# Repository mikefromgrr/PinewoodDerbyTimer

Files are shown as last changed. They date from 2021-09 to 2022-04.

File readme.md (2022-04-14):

# Overview
This is a Pinewood Derby race timer software system designed to run on an ESP32-based microcontroller with support for a 128x32 monochrome SSD1306 OLED screen. Race results are shown on scren and relayed via serial connection (9600,8,N,1). Expects 4 racing lanes. Software tweaks could be made easily to support more (with most of the work to dispaly the results to the OLED screen).

Timing accuracy on the ESP32 hardware below is about two ten-thousandths of a second (0.0002). In other words, it takes .0002 seconds to loop through 4 sensors to determine if they are tripped.

A button press toggles between 3 display modes (race view, lane detection, and raw sensor output).

It's primarily designed to interface with a Windows laptop running the [GrandPrix Race Manager](http://grandprix-software-central.com/index.php/shopping/category/70-grandprix-race-manager) software, though it can likely be used with other derby management software.

### No Support For:
* Racing Light Tree
* Solenoid Gate Releases
* Lane Masking

Though it shouldn't be too difficult to add support for any of these.

## License
You cannot use this software or any derivative of it for commercial purposes (e.g. sell a hardware timer based off of this design/code). 

# Hardware
Designed for ESP32 WeMos Mini D1 ESP-WROOM-32.

## ESP32
* https://www.aliexpress.com/item/1005001621896126.html
* Cost: About $3.81 USD in March 2021, plus shipping.
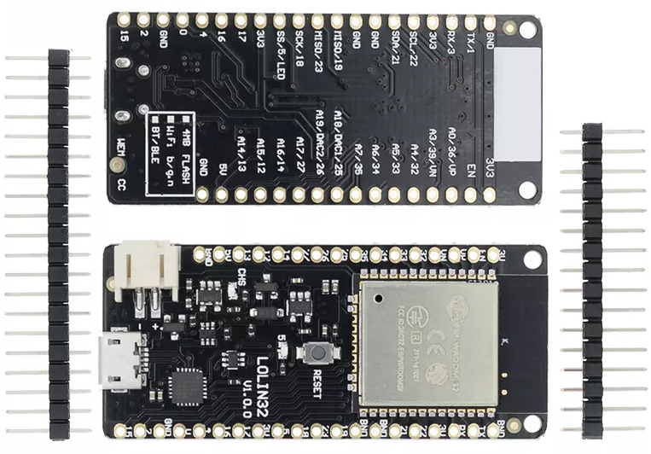
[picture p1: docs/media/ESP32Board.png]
ESP32
* 
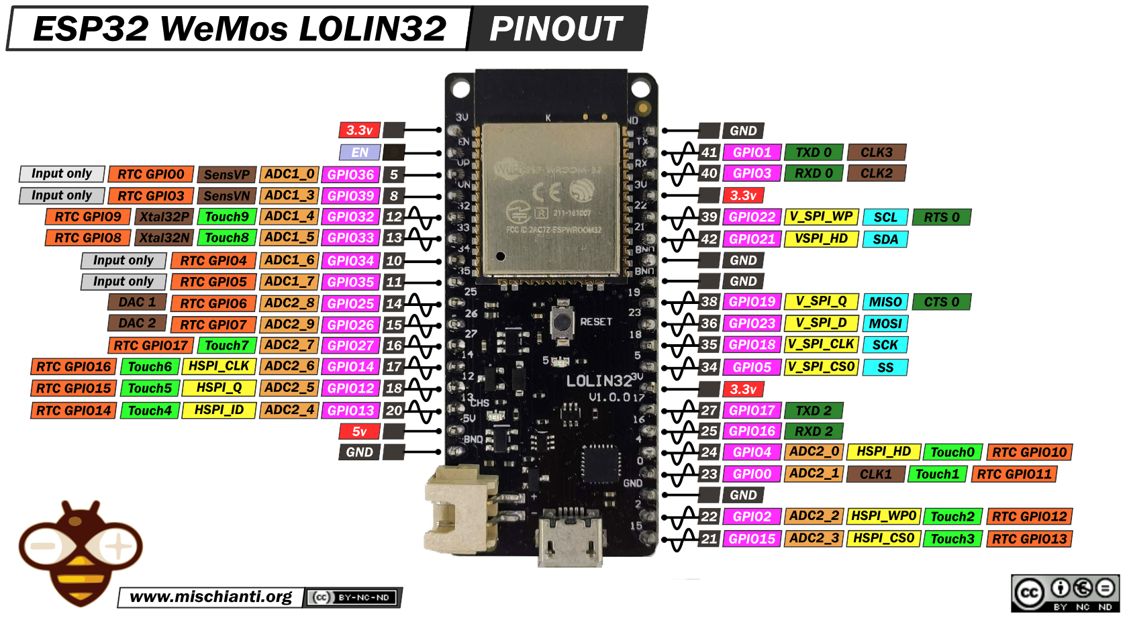
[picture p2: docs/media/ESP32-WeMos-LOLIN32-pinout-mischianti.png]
Pin Out (https://www.mischianti.org/2021/07/30/esp32-wemos-lolin32-lite-high-resolution-pinout-and-specs/ "ESP32 Wemos Lolin32 Pinout")
* 

## SSD1306 Serial OLED Screen
* https://www.aliexpress.com/item/1005001621806398.html
* Cost: About $1.80 USD in July 2021, plus shipping.
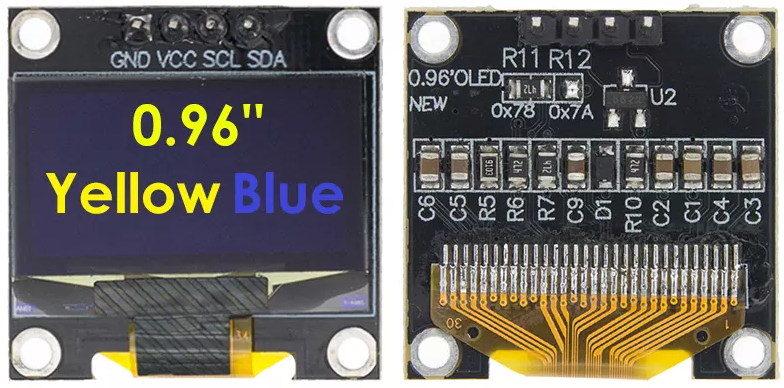
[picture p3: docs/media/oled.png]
SSD1306
* 

## Other
* 2 Small LEDs (for gate status and racing status)
* Light-base lane sensors (tested with a set from an ancient [NewBold DT8000 Timer](https://www.pinewood-derby-timer.com/DT8000.html)); imagine most should work; software reads analog sensor expecting a fully-lit condition to register 4095, and a tripped-condition to be 3500 or less, though this can be tweaked in the code
* Miscellaneous Lane Connectors
* Gate Connector
* [Tactile Push Button Switches](https://www.aliexpress.com/item/32814651113.html)
* [3D Printable Enclosure - Fusion 360 File](docs/3D/ESP32DerbyRaceTimerBox].f3d)

# Compilation
Use [VSCode](https://code.visualstudio.com/Download). Install [PlatformIO extension](https://docs.platformio.org/en/latest/integration/ide/vscode.html). See [platformio.ini](platformio.ini) for configuration details.

# GrandPrix Race Manager Setups
Tested on GPRM15 and GPRM20. See [details here](http://grandprix-software-central.com/index.php/software/faq/search/cat/10-hardware-settings#faq_95).
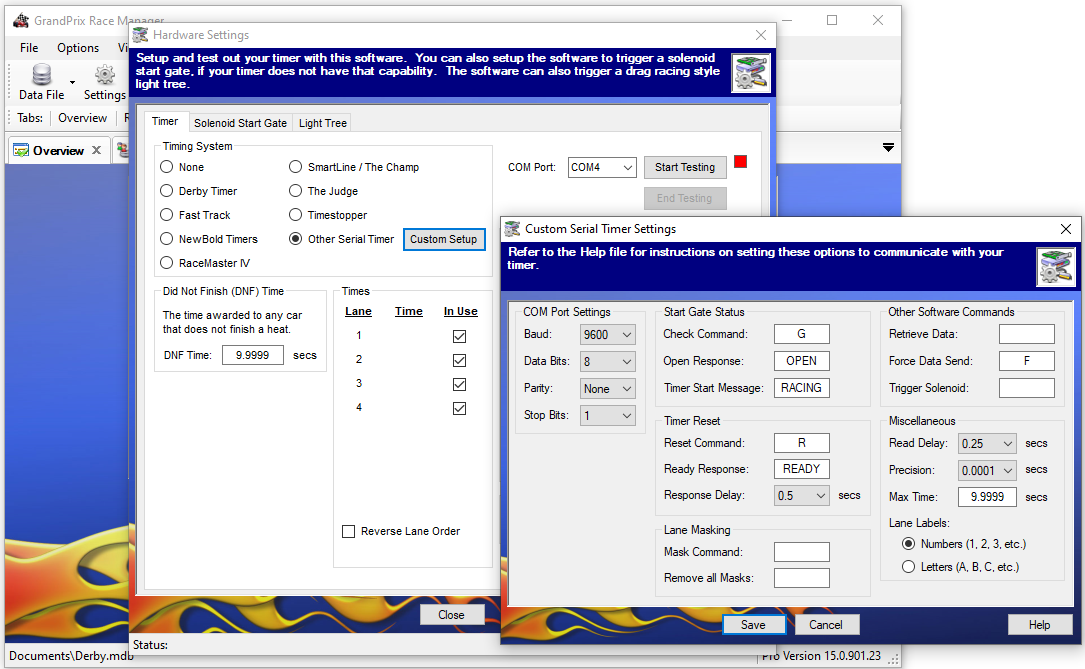
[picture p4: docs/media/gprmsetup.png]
GrandPrix Race Manager Setup


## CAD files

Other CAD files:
docs/3D/ESP32DerbyRaceTimerBox].f3d

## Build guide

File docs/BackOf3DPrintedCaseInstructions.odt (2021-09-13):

Use micro USB connector to connect PC. Designed to work with exactly 4 lanes, no more, no less. Lane pins 1 thru 4 are the farthest from the gate switch. Press mode button to see lane status. When connected and lanes are fully lit, numbers should read a steady 4095. Polarity of lane connectors are important. When cars pass over sensors, shadows are cast and the sensor reads lower. Launch gate needs a complete circuit to read ready (green LED). When racing, purple LED is illuminated.

Driver (if needed)

Silicon Labs CP210x USB to UART Bridge https://www.silabs.com/developers/usb-to-uart-bridge-vcp-drivers

Source Code and More Info

https://github.com/mikefromgrr/PinewoodDerbyTimer

Print and affix to back of 3D Printed case.

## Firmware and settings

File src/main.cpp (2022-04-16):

#include <Arduino.h>
#include <Bounce2.h>
#include <SPI.h>
#include <Wire.h>
#include <TimerScreen.h>

// ESP32 WROOM32 Lolin Pinout: https://www.mischianti.org/wp-content/uploads/2020/11/ESP32-WeMos-LOLIN32-pinout-mischianti.png
// More Details: https://www.mischianti.org/2021/07/30/esp32-wemos-lolin32-lite-high-resolution-pinout-and-specs/
#define TRIGGER_PIN 2                   //connect to GND
#define RACING_LED 17                   //connect negative/cathode lead to GND
#define RACING_LED_CHANNEL 1
#define GATESTATUS_LED 16               //connect negative/cathode lead to GND
#define GATESTATUS_LED_CHANNEL 0        //for PWM Dimming
#define MODESWITCH_PIN 12               //connect to GND
#define EXTRABUTTON_PIN 14              //future use, connect to GND
#define SENSOR_THRESHOLD 3500
#define MAX_RACE_TIME_IN_SECONDS 9.9999
#define BRIGHTNESS_LOW 10
#define BRIGHTNESS_OFF 0

// https://grandprix-software-central.com/index.php/software/faq/faq/95-gprm-custom - Details for GPRM
#define COMMAND_GATE_CHECK 'G'                         //This command will ask the timer to check if the start gate is open or not.
#define COMMAND_TIMER_RESET 'R'                        //This command will tell the timer to reset itself so it is ready for the next heat. Any results or indications of finish order should be cleared from the computer screen and the timer's display.
#define COMMAND_FORCE_DATA_SEND 'F'                    //This command is used if you want to halt the timing (e.g. a car doesn't finish or there is an empty lane). If supported by the timer, pressing the Escape key will prompt the timer to return whatever data that it does have. In this case, any cars that had not finished will be given the maximum time. This command is not necessary if the timer sends the data for a lane as soon as the lane has finished timing. If the timer doesn't support this command, then you must wait until the timer times out before the results will be displayed on screen.
const char *RESPONSE_TIMER_READY = "READY";            //This command will tell the timer to reset itself so it is ready for the next heat. Any results or indications of finish order should be cleared from the computer screen and the timer's display.
const char *RESPONSE_GATE_OPEN = "GATE OPEN";          //This is the response that the timer will send back to indicate that the start gate is open.
const char *RESPONSE_GATE_CLOSED = "GATE CLOSED";      //This is the response that the timer will send back to indicate that the start gate is closed.
const char *RESPONSE_TIMER_STARTED_MESSAGE = "RACING"; //This is the message that the timer will send back to indicate that the heat has started (start gate has opened).
const uint8_t LANE_PINS[8] = {33, 32, 39, 36, 34, 35, 25, 26}; // 1st four are right, unsure about the rest
const short SCREENMODE_LANETIMES = 0;
const short SCREENMODE_SENSOR_OUTPUT = 1;
const short SCREENMODE_LANE_SUMMARY = 2;
const short SCREENMODE_SOFTWARE_IS_RACE_READY = 3;
const unsigned long MAX_LONG = 4294967295;
short LED_PIN = LED_BUILTIN;

using namespace std;

enum LaneStatus
{
  Racing,
  Finished,
  TooSlow,
  NotInUse // lane cannot be found during boot
};
enum TriggerStatus // aka Gate
{
  ReadyToRelease,
  Released
};
enum RaceStatus
{
  Idle,
  RaceInProgress,
  RaceDone
};
struct LaneInfo
{
  unsigned int pin;
  int laneNumber;
  LaneStatus status;
  unsigned long finishTime;
  unsigned long raceDuration;
};


// Global Variables
RaceStatus raceStatus;
TriggerStatus triggerStatus;

unsigned long raceBegin = 0;
unsigned long raceEnd = 0;
short NUM_LANES = 4; // Number of lanes the device is capable to monitor.
short screenMode = 0; 

TimerScreen screen;
Bounce trigger = Bounce();
Bounce screenModeButton = Bounce();
Bounce extraButton = Bounce();
vector<LaneInfo> Lanes; // essentially an array of Lanes

// Computes the time in seconds from beginning of race
float getTimeInSeconds(long durationInMicros)
{
  return (durationInMicros / 1000000.0);
}

// Computes the time in seconds from beginning of race
unsigned long computeDuration(unsigned long raceBeginTime, unsigned long endTime)
{
  unsigned long durationInMicros = 0;
  if (endTime < raceBeginTime)
  {
    // We overflowed the micros() limit (about every 50 minutes of ON time)
    durationInMicros = (MAX_LONG - raceBeginTime) + endTime;
  }
  else
  {
    durationInMicros = endTime - raceBeginTime;
  }
  return durationInMicros;
}

RaceStatus checkForTooLongOfARace()
{
  unsigned long currentMicros = micros();
  long currentDuration = computeDuration(raceBegin, currentMicros);
  if (getTimeInSeconds(currentDuration) > MAX_RACE_TIME_IN_SECONDS)
  {
    // Abort race, too long;
    for (auto& lane : Lanes)
    {
      if (lane.status != Finished)
      {
        lane.raceDuration = (MAX_RACE_TIME_IN_SECONDS * 1000000);
        lane.finishTime = 0;
        lane.status = TooSlow;
      }
    }
    raceEnd = currentMicros;
    return RaceDone;
  }
  return RaceInProgress;
}

RaceStatus pollLanes()
{
  // Poll lanes
  unsigned short int finishCount = 0;
  unsigned long currentMicros = micros();
  for (auto& lane : Lanes)
  {
    if (lane.status == Racing)
    {
      uint16_t sensorValue = analogRead(LANE_PINS[lane.pin]);
      // if (random(1, 10000) > 3) sensorValue = SENSOR_THRESHOLD + 1; //introduce some randomness for testing the sort. hey, wheres the unit tests?
      if (sensorValue < SENSOR_THRESHOLD)
      {
        // Sensor tripped, record time
        lane.finishTime = currentMicros;
        lane.raceDuration = computeDuration(raceBegin, currentMicros);
        lane.status = Finished;
        finishCount++;
      }
    }
    else
    {
      // Lane is already finished
      finishCount++;
    }
  }
  if (finishCount >= NUM_LANES)
  {
    raceEnd = micros();
    return RaceDone;
  }

  return checkForTooLongOfARace();
}

void initializeLanesForRacing(LaneStatus newLaneStatus)
{
  for (auto& lane : Lanes)
  {
    lane.finishTime = 0;
    lane.raceDuration = 0;
    lane.status = newLaneStatus;
  }
}

TriggerStatus getTriggerStatus(int input)
{
  if (input == LOW)
  {
    return ReadyToRelease;
  }
  return Released;
}

void AdjustIndicatorLED(short channel, short brightness) {
  ledcWrite(channel, brightness);
}

void detectPresenceOfLanes() {
    // Clear and reserve space in the Lanes vector/array
    Lanes.clear();
    Lanes.reserve(NUM_LANES);
    
    // Detect and register lanes
    unsigned short int activeLaneCount = 0;
    for (unsigned short int i = 0; i < NUM_LANES; i++)
    {
      uint16_t sensorValue = analogRead(LANE_PINS[i]);
      LaneStatus ls = Finished;
      if (sensorValue < SENSOR_THRESHOLD) {
        ls = NotInUse;
      } else {
        activeLaneCount++;
      }
      Lanes.push_back((struct LaneInfo){.pin=i, .laneNumber=i+1, .status=ls, .finishTime = 0, .raceDuration = 0});
    }
  
    char buffer[200]; 
    String result;
    result.clear(); 
    
    sprintf(buffer,"Detected\n%d Lanes\n", activeLaneCount);
    result.concat(buffer);

    // List Lane Numbers
    for (auto& lane : Lanes)
    {
      sprintf(buffer,"%i", lane.laneNumber);
      result.concat(buffer);
    }

    result.concat('\n');

    // List Lane Status
    for (auto& li : Lanes)
    {
      if (li.status == NotInUse) {
        sprintf(buffer,"X");
      } else {
        sprintf(buffer,"%i", li.laneNumber);
      }

      result.concat(buffer);
    }

    // Output to Screen
    Serial.println(result);
    screen.displayResults(result);
}

void setup()
{
  Serial.begin(9600);
  raceStatus = Idle;

  // LED SETUP
  pinMode(LED_PIN, OUTPUT);
  digitalWrite(LED_PIN, LOW);

  // INDICATOR LED SETUP, driven by PWM
  ledcSetup(GATESTATUS_LED_CHANNEL, 2500, 8);
  ledcSetup(RACING_LED_CHANNEL, 2500, 8);
  ledcAttachPin(GATESTATUS_LED, GATESTATUS_LED_CHANNEL);
  ledcAttachPin(RACING_LED, RACING_LED_CHANNEL);

  // Screen Setup
  screen = TimerScreen();
  screen.setup();
  screen.print("Booted...");

  // Gate/Trigger Setup
  trigger.attach(TRIGGER_PIN, INPUT_PULLUP); // USE EXTERNAL PULL-UP
  trigger.interval(5); // DEBOUNCE INTERVAL IN MILLISECONDS
  trigger.update();
  triggerStatus = getTriggerStatus(trigger.read());

  // Screen Mode Button Toggler Setup
  screenModeButton.attach(MODESWITCH_PIN, INPUT_PULLUP); // USE EXTERNAL PULL-UP
  screenModeButton.interval(100); // DEBOUNCE INTERVAL IN MILLISECONDS
  screenModeButton.update();

  // Extra Button Setup
  extraButton.attach(EXTRABUTTON_PIN, INPUT_PULLUP); // USE EXTERNAL PULL-UP
  extraButton.interval(100); // DEBOUNCE INTERVAL IN MILLISECONDS
  extraButton.update();

  detectPresenceOfLanes();

}

// Sorting Functions
auto laneTimeSorterFunction = [](LaneInfo a, LaneInfo b) { return a.raceDuration < b.raceDuration; };
auto laneNumberSorterFunction = [](LaneInfo a, LaneInfo b) { return a.laneNumber < b.laneNumber; };

void outputRaceTimes()
{
  char buffer[200];
  String result;
  result.clear(); 
  
  sort(Lanes.begin(), Lanes.end(), laneTimeSorterFunction);

  for (auto& lane : Lanes) {
    sprintf(buffer,"%d %3.4f\n", lane.laneNumber, getTimeInSeconds(lane.raceDuration));
    result.concat(buffer);
  }
  Serial.println(result);
  screen.displayResults(result);
}

void outputSensorReadouts()
{
  char buffer[200];
  String result;
  result.clear();

  sort(Lanes.begin(), Lanes.end(), laneNumberSorterFunction);

  for (auto& lane : Lanes)
  {
    uint16_t sensorValue = analogRead(LANE_PINS[lane.pin]);
    sprintf(buffer,"%d %d\n", lane.laneNumber, sensorValue);
    result.concat(buffer);
  }
  screen.displaySensorReadout(result);
}


void updateLEDs()
{
  if (raceStatus == RaceInProgress)
  {
    digitalWrite(LED_PIN, LOW);
    AdjustIndicatorLED(RACING_LED_CHANNEL, BRIGHTNESS_LOW);
  }
  else
  {
    digitalWrite(LED_PIN, HIGH);
    AdjustIndicatorLED(RACING_LED_CHANNEL, BRIGHTNESS_OFF);
  }

  if (triggerStatus == ReadyToRelease) {
    AdjustIndicatorLED(GATESTATUS_LED_CHANNEL, BRIGHTNESS_LOW);
  }
  else 
  {
    AdjustIndicatorLED(GATESTATUS_LED_CHANNEL, BRIGHTNESS_OFF);
  }
}

void processCurrentScreenMode() {
  switch (screenMode)
  {
    case SCREENMODE_LANETIMES:
      outputRaceTimes();
      break;
    case SCREENMODE_SENSOR_OUTPUT:
      detectPresenceOfLanes();
      break;
    case SCREENMODE_LANE_SUMMARY:
      detectPresenceOfLanes();
      break;
    case SCREENMODE_SOFTWARE_IS_RACE_READY:
      screen.print("Software\nawaiting\nrace\nstart.");
      break;
    default:
      Serial.println("Unknown screenMode");
      break;
  }
}

void loop()
{

  // Check for Gate Trigger
  trigger.update();
  if (trigger.changed())
  {
    int debouncedTriggerInput = trigger.read();
    triggerStatus = getTriggerStatus(debouncedTriggerInput);
    if (raceStatus != RaceInProgress && triggerStatus == Released)
    {
      raceBegin = micros();
      initializeLanesForRacing(Racing);
      Serial.println(RESPONSE_TIMER_STARTED_MESSAGE);
      raceStatus = RaceInProgress;
      screenMode = SCREENMODE_LANETIMES;
      screen.print("Race\nIn\nProgress");
      updateLEDs();
    }
  }

  // Button Presses
  extraButton.update();
  screenModeButton.update();

  if (extraButton.read() == LOW) {
    // Print message so user doens't think button is broken.
    // Shown only when button is held.
    screen.print("This\nbutton\ndoes\nnothing.");
  } else {
    if (screenModeButton.fell())
    {
      screenMode++;
      if(screenMode > 2) screenMode = 0;
      processCurrentScreenMode();
    }

    if(screenMode == SCREENMODE_SENSOR_OUTPUT) {
      outputSensorReadouts();
    }
  }

  if (extraButton.rose()) {
    // Returns screen to prior state
    processCurrentScreenMode();
  }

  // Update the LEDs to proper status
  updateLEDs();

  // Handle state changes
  switch (raceStatus)
  {
  case RaceInProgress:
    raceStatus = pollLanes();
    break;
  case RaceDone:
    screenMode = SCREENMODE_LANETIMES;
    outputRaceTimes();
    raceStatus = Idle;
    break;
  case Idle:
    break;
  default:
    Serial.println("Unknown Status");
    break;
  }

  // Sniff for incoming commands from software via the serial connection
  int incomingByte = 0; // for incoming serial data
  if (Serial.available() > 0)
  {
    // Read the incoming byte
    incomingByte = Serial.read();
    switch (incomingByte)
    {
    case COMMAND_GATE_CHECK:
      if (triggerStatus == ReadyToRelease)
      {
        Serial.println(RESPONSE_GATE_CLOSED);
      }
      else
      {
        Serial.println(RESPONSE_GATE_OPEN);
      }
      break;
    case COMMAND_FORCE_DATA_SEND:
      outputRaceTimes(); //TODO This really isn't fully/properly implemented.
      break;
    case COMMAND_TIMER_RESET:
      initializeLanesForRacing(Finished);
      if (triggerStatus == ReadyToRelease)
      {
        Serial.println(RESPONSE_TIMER_READY);
        screenMode = SCREENMODE_SOFTWARE_IS_RACE_READY;
        raceStatus = Idle;
        processCurrentScreenMode();
      }
      else
      {
        Serial.println(RESPONSE_GATE_OPEN); 
      }
    default:
      break;
    }
  }
}

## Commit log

2021-06-15 Switch Lanes[] array to vector so sort() could work.
2021-06-20 Bunches of changes.
    Add Sensor readouts. Add LEDs and buttons to help with screen mode and racing/gate indicator lights. Refactor to have precise too-slow finish times.
2021-09-06 Add documentation.
    [ESP32DerbyRaceTimerBox].f3d]
2021-09-13 Add extra button message.
    Add message to show when extra button is pressed. In this, case nothing. Can be used for something else.
2021-09-13 Add printed "instructions".
    Affix to back of 3D Printed case.
2022-04-14 Fix erratic sort() bug.
    Mixing the for(i) loop and vector.sort() syntax wasn't compatible. Led to misreporting results unless the timer was reinitialized between races. Altered looping operations to use for(auto&) syntax for the win.
    [main.cpp]
